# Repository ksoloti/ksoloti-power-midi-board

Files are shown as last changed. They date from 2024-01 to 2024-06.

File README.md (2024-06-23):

# Ksoloti Power MIDI addon board

Kicad 6+

Libraries not included, you should be able to retrieve any custom symbols and footprints via the project itself.

3D models not included, always such a hassle with those files, can't be a%$ed.

Gerbers, BOM and CPL (placement) files for JLC included. You should be able to have the board with all SMD parts produced. The remaining (through-hole) parts required are all quite common: 2.54mm headers, DIN-5 MIDI jacks, DC barrel jack...

## Disclaimer: the files are provided as is. I guarantee nothing. Stay safe and double check. If you're not sure if you're doing it right, ask someone with more knowledge for help.

## Schematic
[ksoloti-power-midi-board.pdf](ksoloti-power-midi-board.pdf)

## Rear
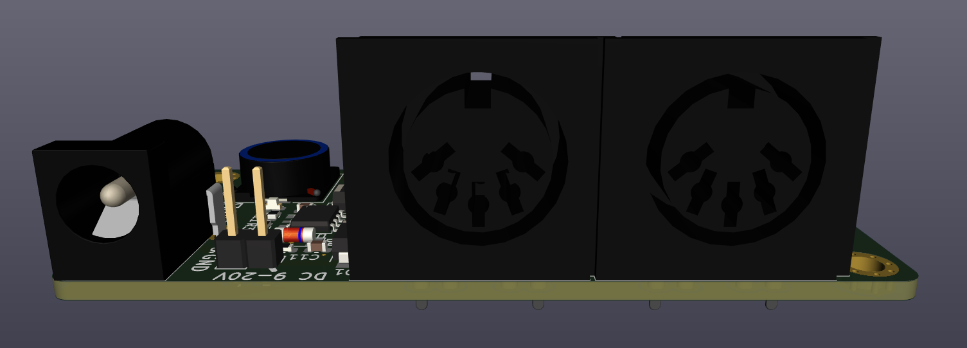
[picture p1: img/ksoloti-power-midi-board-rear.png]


## Front
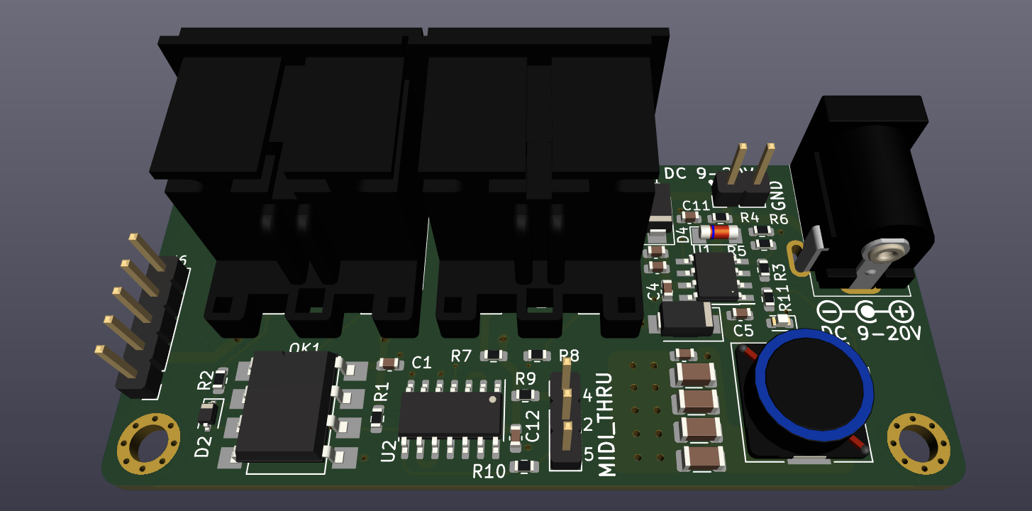
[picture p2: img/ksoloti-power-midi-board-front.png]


## Bottom
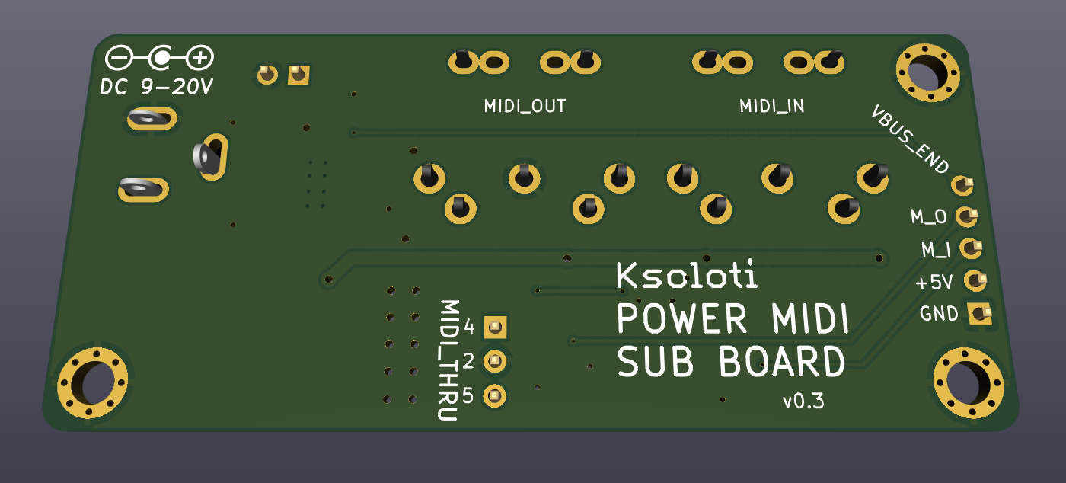
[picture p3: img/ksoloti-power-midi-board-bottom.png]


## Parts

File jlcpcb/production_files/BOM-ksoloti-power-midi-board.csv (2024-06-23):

Comment | Designator | Footprint | LCSC
100n | C1,C11,C12,C4,C6 | C_0603_1608Metric | C14663
6N137 | OK1 | SMDIP-8_W9.53mm | C16496
1N4148WS | D2 | D_SOD-323 | C2128
LED | D5 | LED_0603_1608Metric | C2286
220 | R10,R2,R5,R7,R8,R9 | R_0603_1608Metric | C22962
10k | R1,R11,R3 | R_0603_1608Metric | C25804
47k | R4 | R_0603_1608Metric | C25819
15uh | L1 | L_10.4x10.4_H4.8 | C2847544
3k | R6 | R_0603_1608Metric | C4211
74HC14 | U2 | SOIC-14_3.9x8.7mm_P1.27mm | C5605
10n | C5 | C_0603_1608Metric | C57112
3V3 | D4 | D_MiniMELF | C707189
SS34 | D1,D3 | D_SMA | C8678
47u | C10,C7,C8,C9 | C_1206_3216Metric | C96123
10u | C2,C3 | C_0603_1608Metric | C96446
TPS5430DDA | U1 | TI_SO-PowerPAD-8_ThermalVias | C9864
MountingHole_Pad | H3 | MountingHole_3.2mm_M3_Pad_Via_tight
VIN | J1 | PinHeader_1x02_P2.54mm_Vertical
MountingHole_Pad | H2 | MountingHole_3.2mm_M3_Pad_Via_tight
MIDI_THRU | J5 | PinHeader_1x03_P2.54mm_Vertical
DC 9-20V | J2 | dc_socket
BREAKOUT_CONN | J6 | PinHeader_1x05_P2.54mm_Vertical
MIDI_IN | J3 | MIDI_DIN-5_DS-5-01c
MountingHole_Pad | H1 | MountingHole_3.2mm_M3_Pad_Via_tight
MIDI_OUT | J4 | MIDI_DIN-5_DS-5-01c

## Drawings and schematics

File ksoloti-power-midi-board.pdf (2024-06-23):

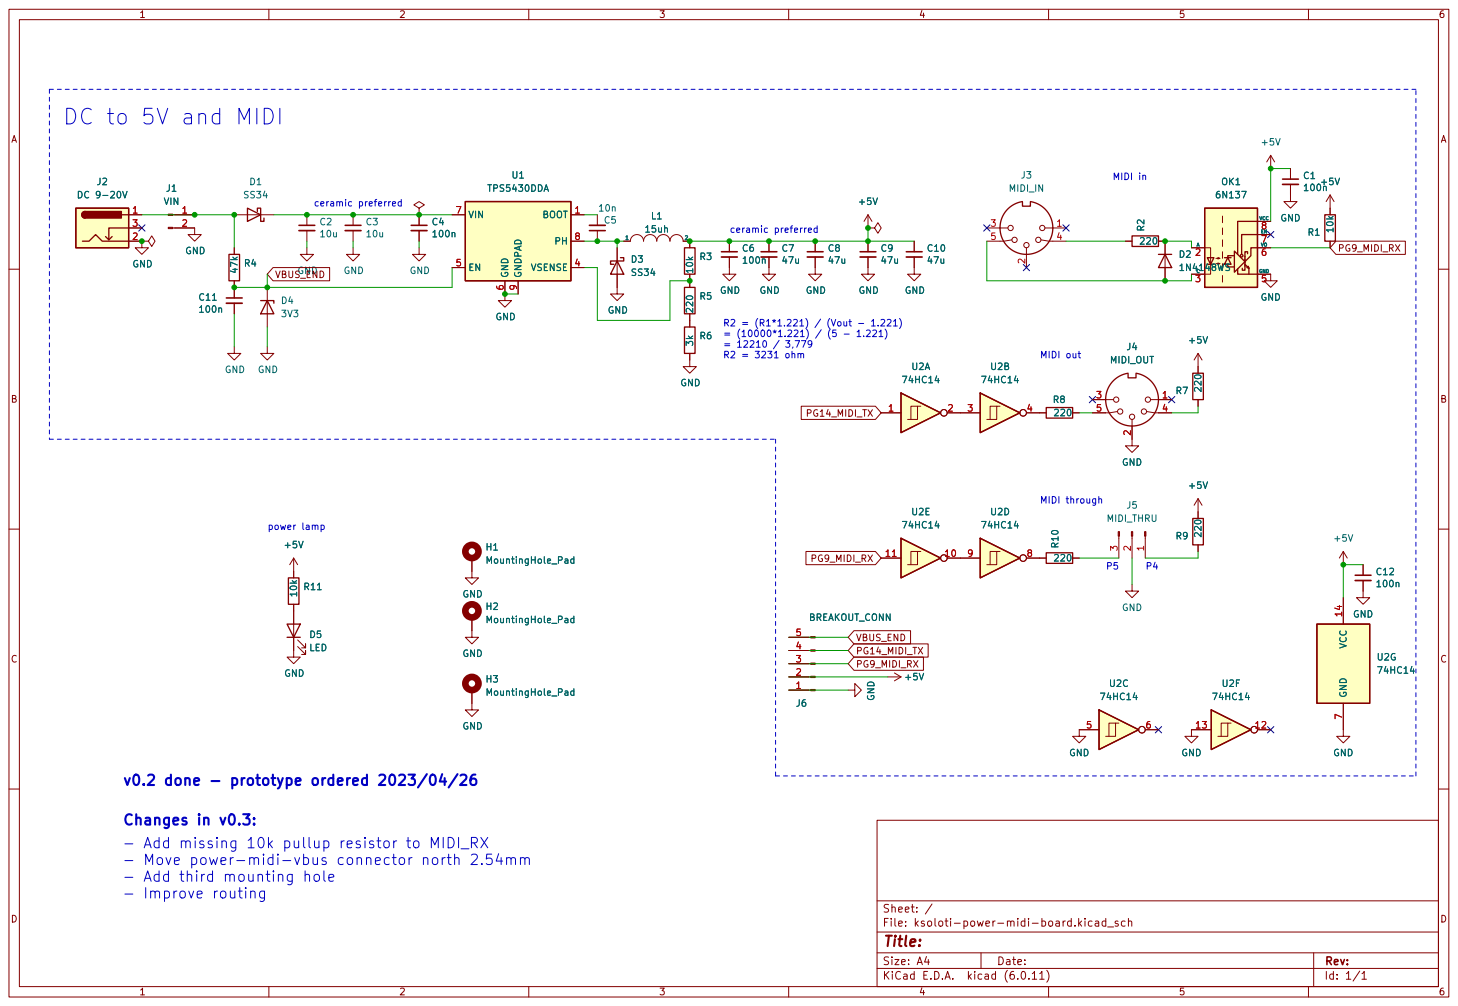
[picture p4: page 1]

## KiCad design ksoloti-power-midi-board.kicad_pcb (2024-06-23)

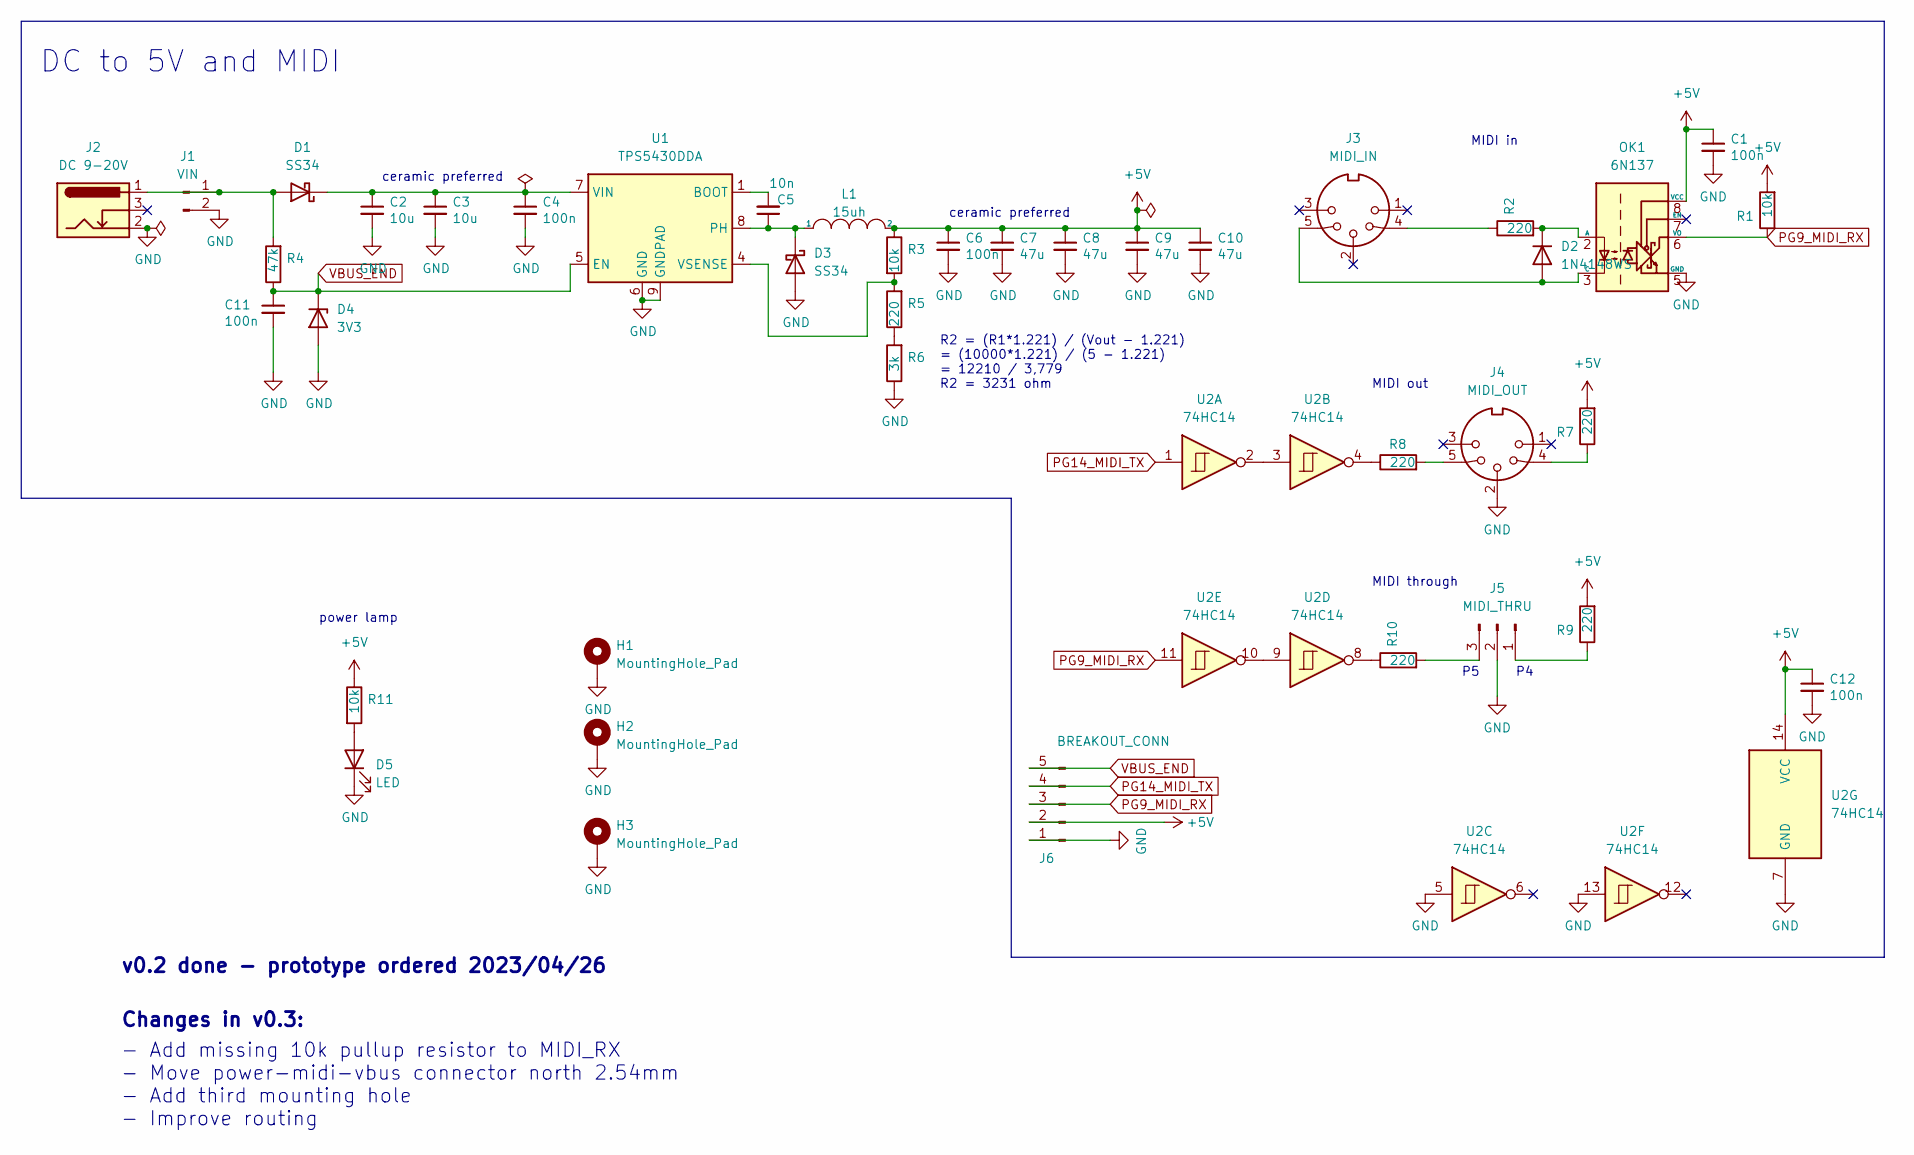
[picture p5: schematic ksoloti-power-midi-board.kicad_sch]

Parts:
C1, C4, C6, C11, C12: 100n; C_0603_1608Metric
C2, C3: 10u; C_0603_1608Metric
C5: 10n; C_0603_1608Metric
C7, C8, C9, C10: 47u; C_1206_3216Metric
D1, D3: SS34; D_SMA
D2: 1N4148WS; D_SOD-323
D4: 3V3; D_MiniMELF
D5: LED; LED_0603_1608Metric
H1, H2, H3: MountingHole_Pad; MountingHole_3.2mm_M3_Pad_Via_tight
J1: VIN; PinHeader_1x02_P2.54mm_Vertical
J2: DC 9-20V; dc_socket
J3: MIDI_IN; MIDI_DIN-5_DS-5-01c
J4: MIDI_OUT; MIDI_DIN-5_DS-5-01c
J5: MIDI_THRU; PinHeader_1x03_P2.54mm_Vertical
J6: BREAKOUT_CONN; PinHeader_1x05_P2.54mm_Vertical
L1: 15uh; L_10.4x10.4_H4.8
OK1: 6N137; SMDIP-8_W9.53mm
R1, R3, R11: 10k; R_0603_1608Metric
R2, R5, R7, R8, R9, R10: 220; R_0603_1608Metric
R4: 47k; R_0603_1608Metric
R6: 3k; R_0603_1608Metric
U1: TPS5430DDA; TI_SO-PowerPAD-8_ThermalVias
U2: 74HC14; SOIC-14_3.9x8.7mm_P1.27mm

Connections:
+5V: C1.1, C6.1, C7.1, C8.1, C9.1, C10.1, C12.1, J6.2, L1.2, OK1.8 (VCC), R1.2, R3.1, R7.2, R9.2, R11.1, U2.14 (VCC)
GND: C1.2, C2.2, C3.2, C4.2, C6.2, C7.2, C8.2, C9.2, C10.2, C11.2, C12.2, D3.2 (A), D4.2 (A), D5.1 (K), H1.1, H2.1, H3.1, J1.2, J2.2, J4.2, J5.2, J6.1, OK1.5 (GND), R6.1, U1.6 (GND), U1.9 (GNDPAD), U2.5, U2.7 (GND), U2.13
unnamed: C2.1, C3.1, C4.1, D1.1 (K), U1.7 (VIN)
unnamed: C5.1, D3.1 (K), L1.1, U1.8 (PH)
unnamed: C5.2, U1.1 (BOOT)
unnamed: D1.2 (A), J1.1, J2.1, R4.2
unnamed: D2.1 (K), OK1.2 (A), R2.2
unnamed: D2.2 (A), J3.5, OK1.3 (C)
unnamed: D5.2 (A), R11.2
unnamed: J3.4, R2.1
unnamed: J4.4, R7.1
unnamed: J4.5, R8.2
unnamed: J5.1, R9.1
unnamed: J5.3, R10.2
unnamed: R3.2, R5.2, U1.4 (VSENSE)
unnamed: R5.1, R6.2
unnamed: R8.1, U2.4
unnamed: R10.1, U2.8
unnamed: U2.2, U2.3
unnamed: U2.9, U2.10
PG9_MIDI_RX: J6.3, OK1.6 (VO), R1.1, U2.11
PG14_MIDI_TX: J6.4, U2.1
VBUS_END: C11.1, D4.1 (K), J6.5, R4.1, U1.5 (EN)

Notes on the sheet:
MIDI out
ceramic preferred
power lamp
DC to 5V and MIDI
- Add missing 10k pullup resistor to MIDI_RX - Move power-midi-vbus connector north 2.54mm - Add third mounting hole - Improve routing
MIDI through
v0.2 done - prototype ordered 2023/04/26
MIDI in
Changes in v0.3:
R2 = (R1*1.221) / (Vout - 1.221) = (10000*1.221) / (5 - 1.221) = 12210 / 3,779 R2 = 3231 ohm

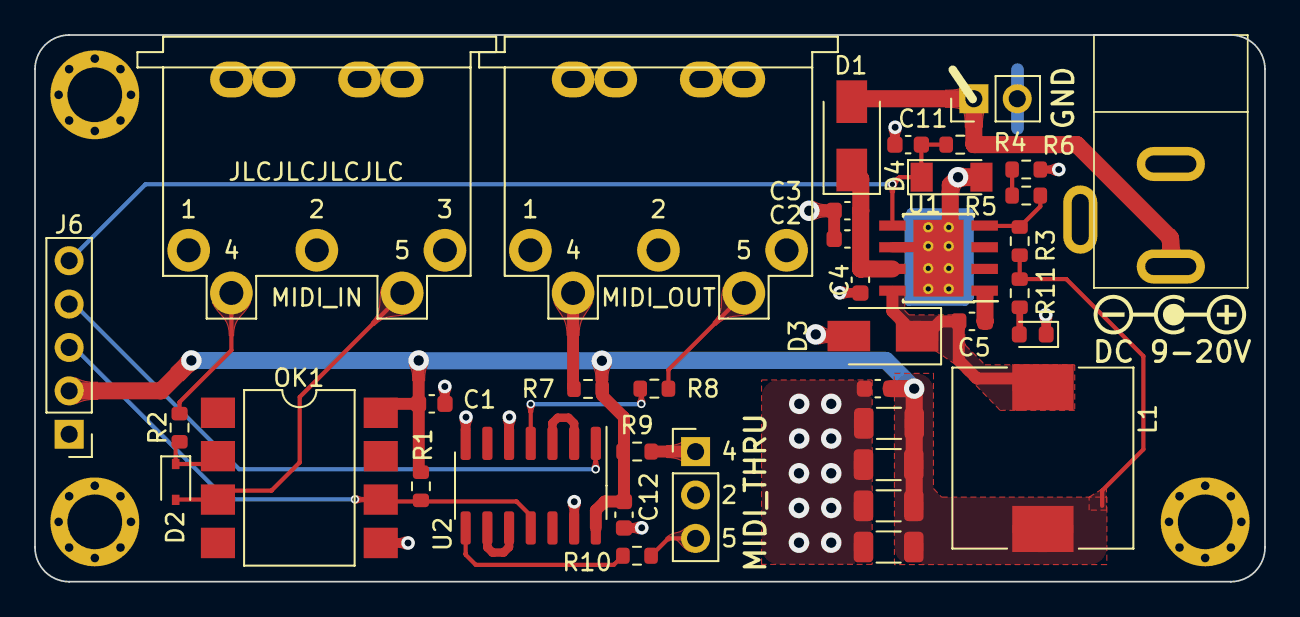
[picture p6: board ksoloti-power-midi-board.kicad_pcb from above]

Board: 2 copper layers, 72.0 x 32.0 mm, 41 parts (0 on the bottom side), 23 nets.

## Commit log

2024-01-03 Kicad gitignore template ignores .csv files, fixed
    [BOM-ksoloti-power-midi-board.csv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]
2024-06-23 add schematic pdf
2024-06-23 edits, update cpl and project.db
    [BOM-ksoloti-power-midi-board.csv, ksoloti-power-midi-board.kicad_pcb, ksoloti-power-midi-board.kicad_sch]
2024-06-23 fix link to schematic
